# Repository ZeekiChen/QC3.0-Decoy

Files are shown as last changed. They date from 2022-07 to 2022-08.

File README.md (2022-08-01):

# QC3.0-Decoy
高精度QC3.0诱骗器  
2022.07.08  
项目发布，上传文件：  
CODE:  
  QC3.0 Decoy-Code-20220706.rar  
HARDWARE:  
  QC3.0 Decoy-Bom.xlsx  
  QC3.0 Decoy-PcbDoc.PcbDoc  
  QC3.0 Decoy-SchDoc.pdf  
  QC3.0 Decoy-丝印图.pdf  
QC3.0 Decoy-参考制作流程.pdf  
QC3.0 Decoy-使用说明.pdf  
QC3.0 Decoy-丝印图.rar  
2022.07.16  
修改Bom表，原Bom表中PMOS的选型Vgs太小，需要Vgs>20v  
涉及到的文件：QC3.0 Decoy-Bom.xlsx  
2022.07.25  
修改Gerber文件，补充NC Drill files  
2022.08.01  
添加固件，新增对使用SSD1312驱动芯片的OLED屏幕的支持  
修改文件名“QC3.0 Decoy-Code-20220706.rar”为“QC3.0 Decoy-Code-USECH1115-20220706.rar”  
上传文件“QC3.0 Decoy-Code-USESSD1312-20220801.rar”  
修改文件“QC3.0 Decoy-参考制作流程.pdf”，修改程序下载部分的固件选择相关说明

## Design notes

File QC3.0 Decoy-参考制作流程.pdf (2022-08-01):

# 制作准备

使用“\HARDWARE\QC3.0 Decoy.PcbDoc”文件打板，两层板，厚度 1.6mm 购买“\HARDWARE\QC3.0 Decoy-Bom.xlsx”表中的电子元器件和相关零件 准备一条 USB 转串口线用于程序烧录

# 一．焊接 PCB

由于板子设计的比较紧凑，每个元件的丝印丝印都被隐藏了，所以焊接板子的时候元件的参 数和位置，请打开“”“\HARDWARE\QC3.0 Decoy-丝印图.pdf”来查看。 焊接过程中需要注意的只有一点，如果你使用风枪进行吹焊，控制风枪温度在 240℃，屏幕 和输出接线端子最后焊接，PCB 背面阻焊开窗处补上一些锡来增加过电流能力。

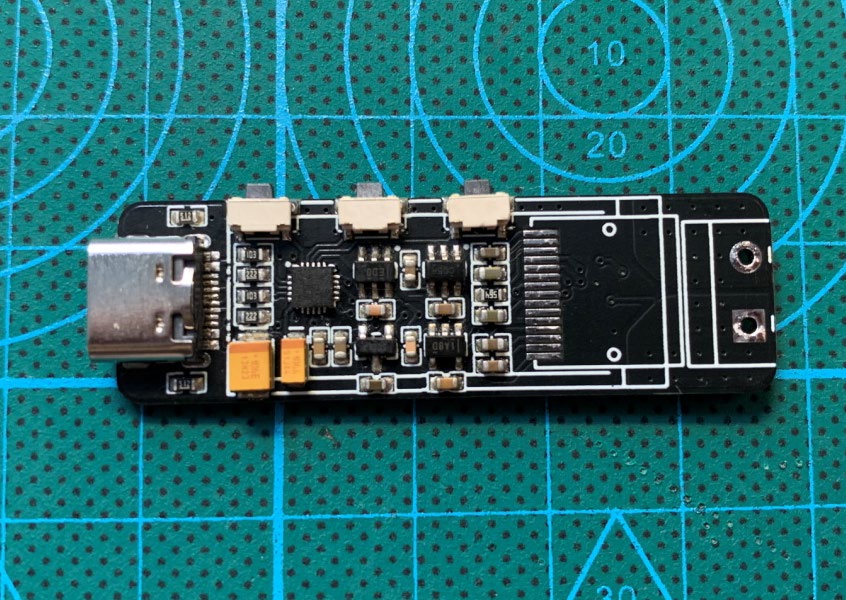
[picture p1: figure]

PCB 正面

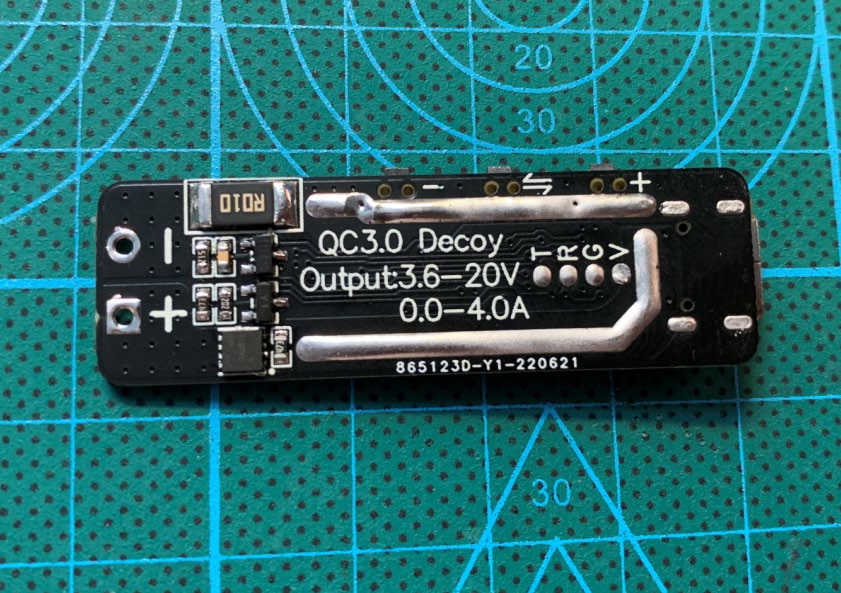
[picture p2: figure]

PCB 背面

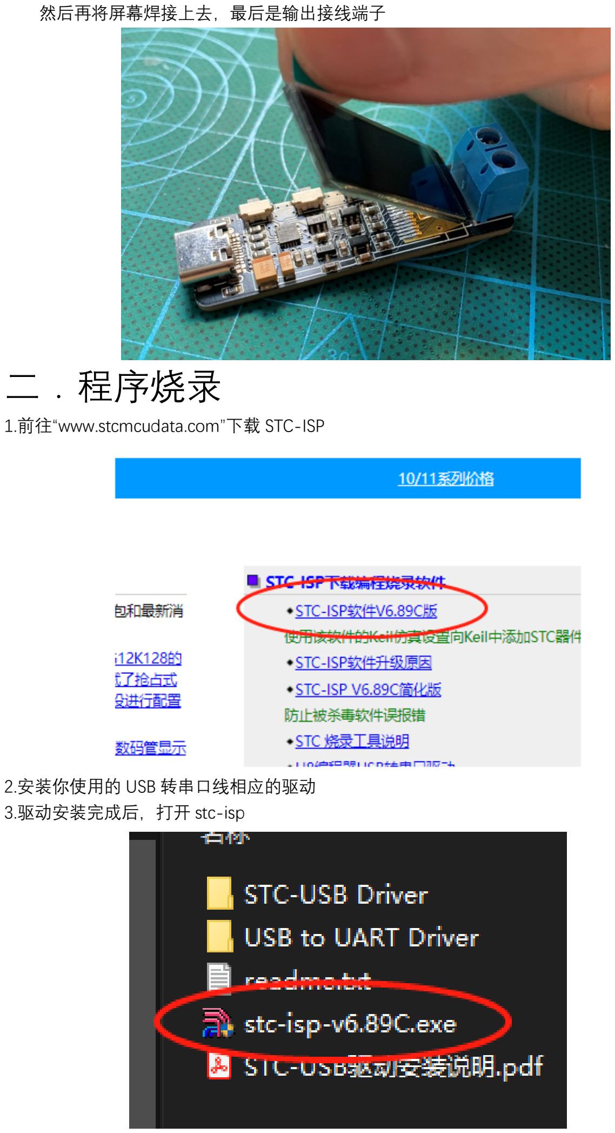
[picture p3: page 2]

然后再将屏幕焊接上去，最后是输出接线端子

# 二．程序烧录

1.前往“www.stcmcudata.com”下载 STC-ISP

2.安装你使用的 USB 转串口线相应的驱动
3.驱动安装完成后，打开 stc-isp

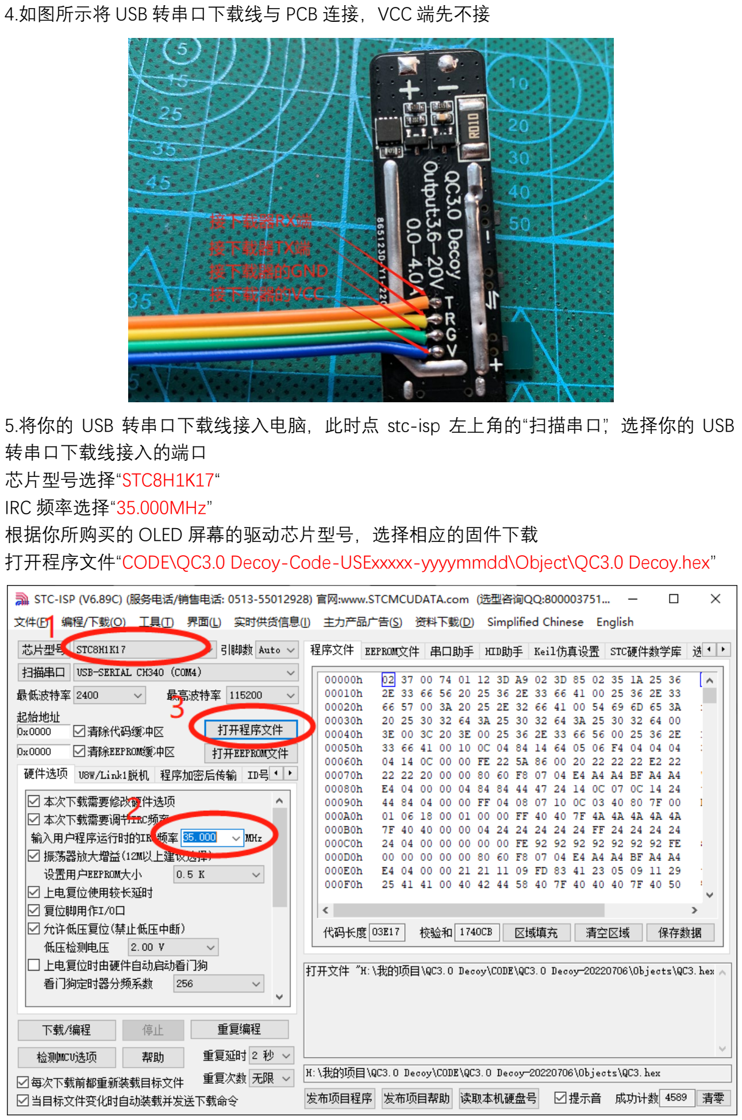
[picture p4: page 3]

4.如图所示将 USB 转串口下载线与 PCB 连接，VCC 端先不接

5.将你的 USB 转串口下载线接入电脑，此时点 stc-isp 左上角的“扫描串口”，选择你的 USB 转串口下载线接入的端口
芯片型号选择“STC8H1K17“
IRC 频率选择“35.000MHz”
根据你所购买的 OLED 屏幕的驱动芯片型号，选择相应的固件下载 打开程序文件“CODE\QC3.0 Decoy-Code-USExxxxx-yyyymmdd\Object\QC3.0 Decoy.hex”

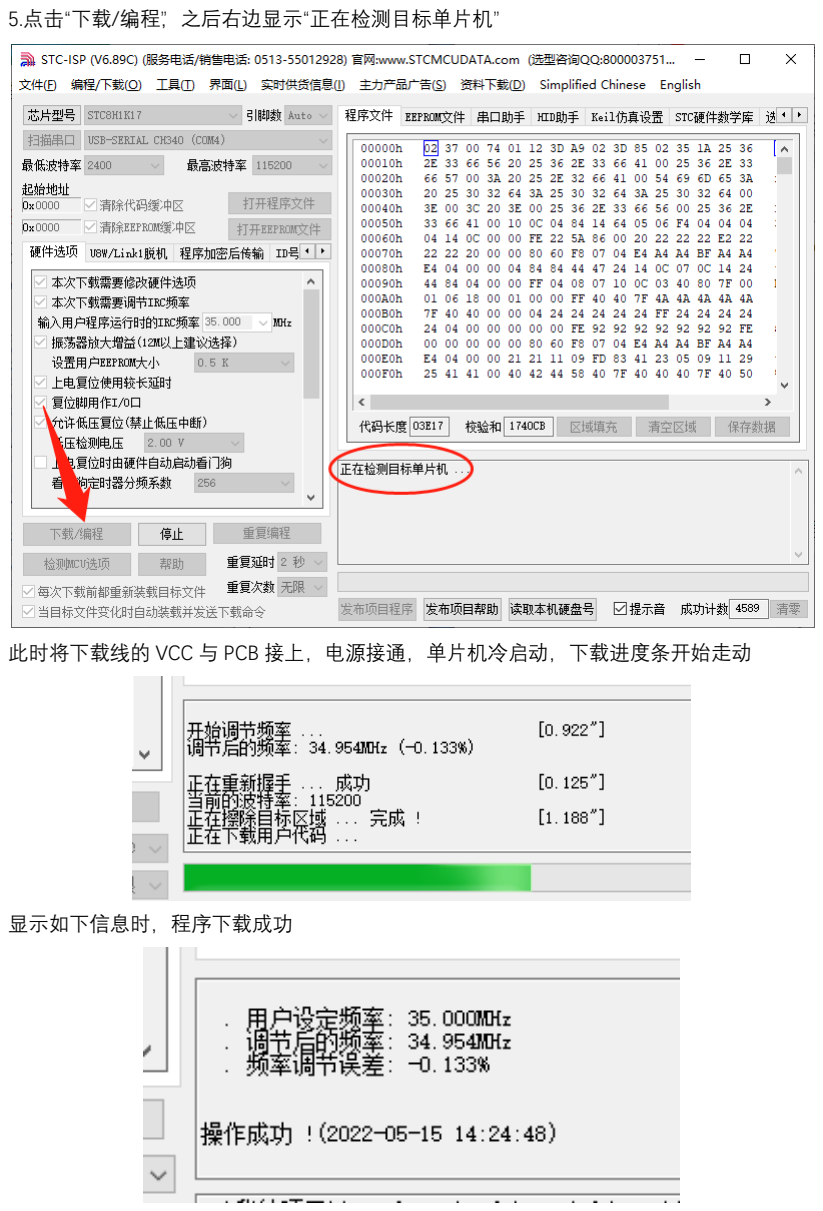
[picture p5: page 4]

5.点击“下载/编程”，之后右边显示“正在检测目标单片机”

此时将下载线的 VCC 与 PCB 接上，电源接通，单片机冷启动，下载进度条开始走动

显示如下信息时，程序下载成功

# 三．测试

将烧录好程序的 PCB，使用兼容 USB2.0 的 Type-C 线接入支持 QC3.0 快充协议的适配器或 者移动电源

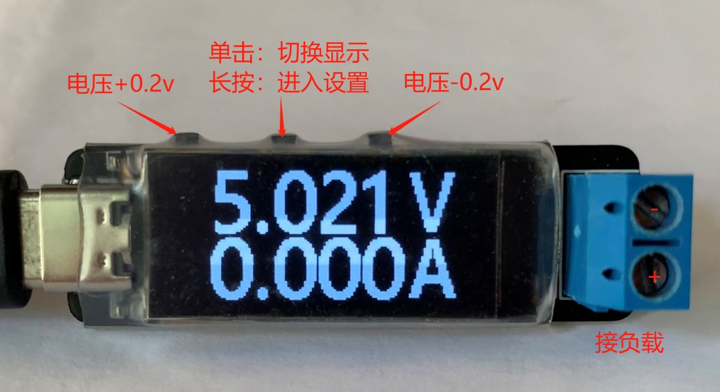
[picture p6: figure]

检查能否诱骗出电压，以及诱骗电压是否能调整，屏幕是否显示，现实的示数是否正常
1. 诱骗电压无法调整：原因可能是 Type-C 接口中 D+/D-端接触不良导致的，也可能是单 片机相应的控制引脚虚焊了
2. 屏幕不显示：原因可能是屏幕排线焊接不良，虚焊或者引脚间连锡，也可能是单片机相 应的控制引脚虚焊
3. 示数不正常：检查 U3,U4,U5 的焊接是否正常，也可能是单片机相应的控制引脚虚焊

# 四．封装

使用直径 13mm 的透明热缩管，裁剪至合适长度

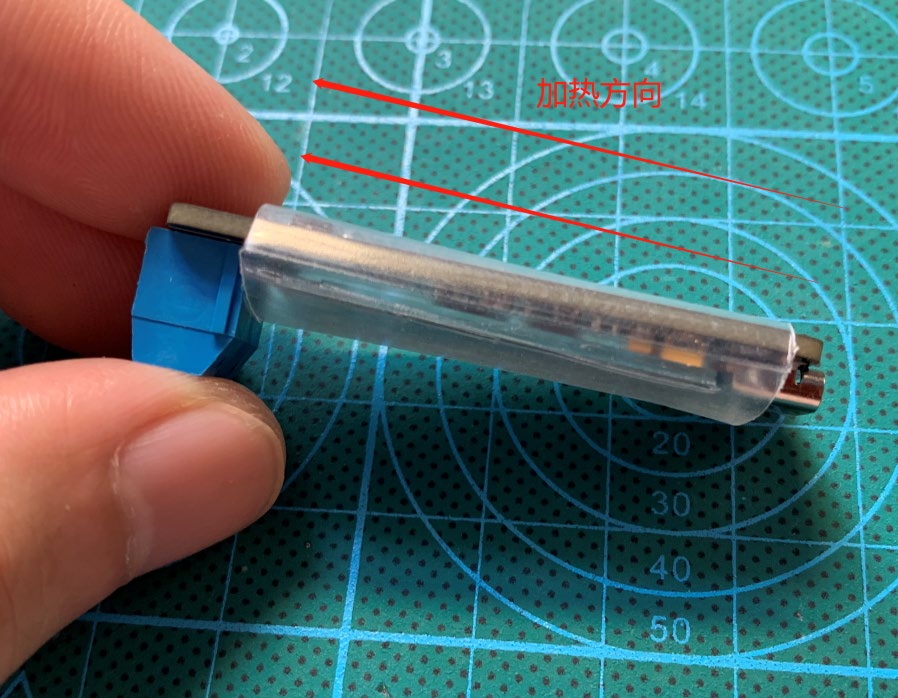
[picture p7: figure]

由于屏幕后端没有支撑，先加热有支撑的地方，使得屏幕与 PCB 平行固定之后，再加热屏 幕后端，注意温度不能过高，控制在 120℃左右，完成后如图所示：

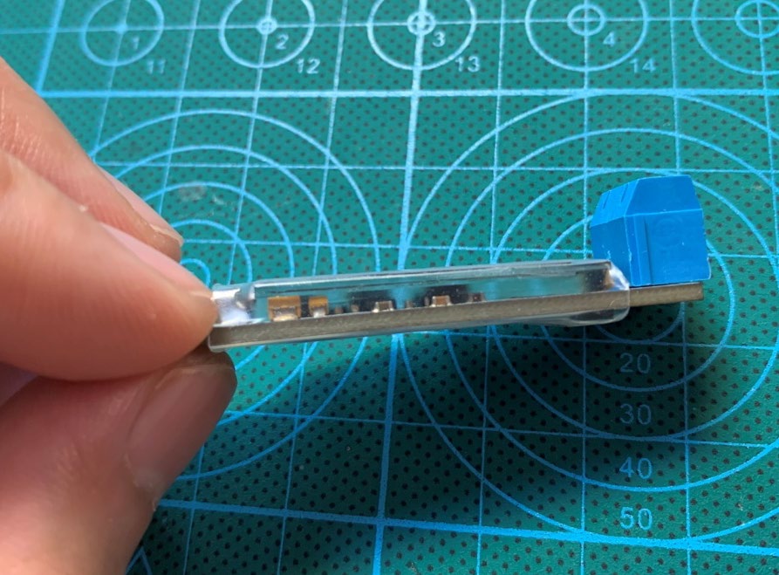
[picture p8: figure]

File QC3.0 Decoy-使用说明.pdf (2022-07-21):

# QC3.0 Decoy 使用说明

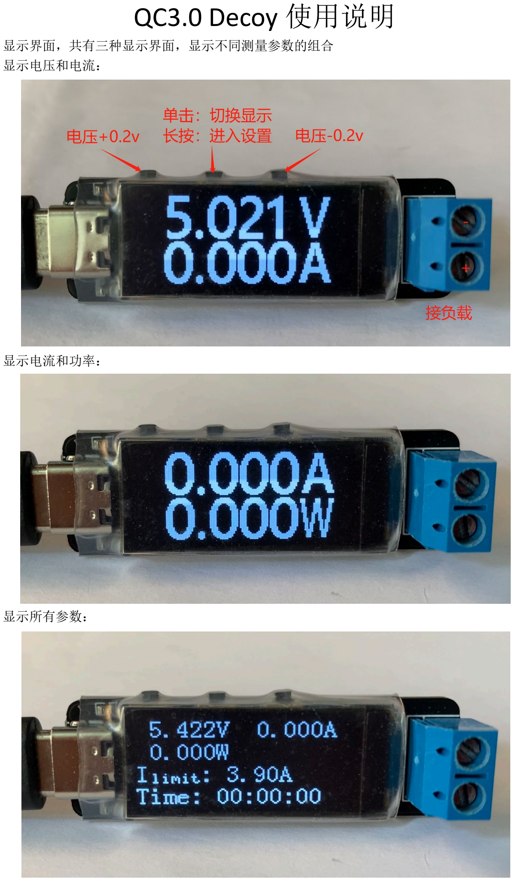
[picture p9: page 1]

显示界面，共有三种显示界面，显示不同测量参数的组合
显示电压和电流：

显示电流和功率：

显示所有参数：

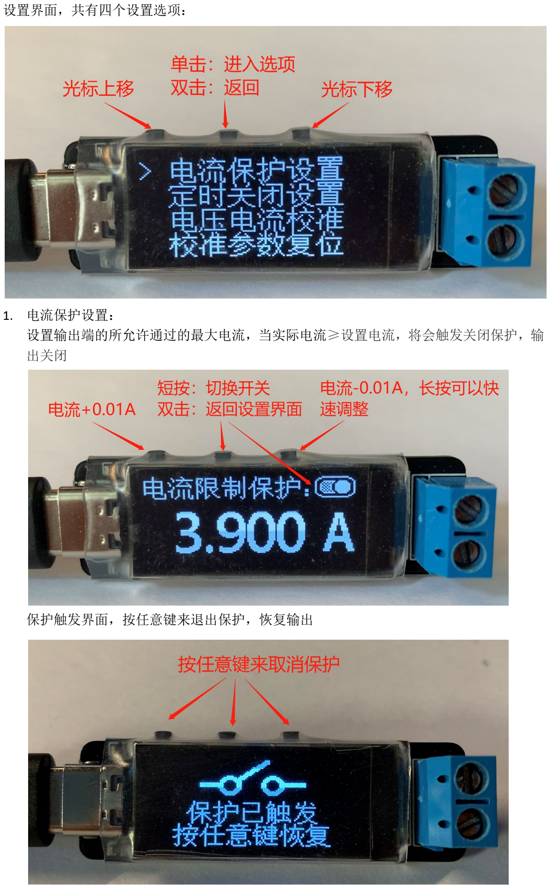
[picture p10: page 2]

设置界面，共有四个设置选项：

1. 电流保护设置：
设置输出端的所允许通过的最大电流，当实际电流≥设置电流，将会触发关闭保护，输 出关闭

保护触发界面，按任意键来退出保护，恢复输出

2. 定时关闭设置
设置多长时间后，输出关闭，单位为“时:分:秒”，可设置的最大时间为 99:59:59

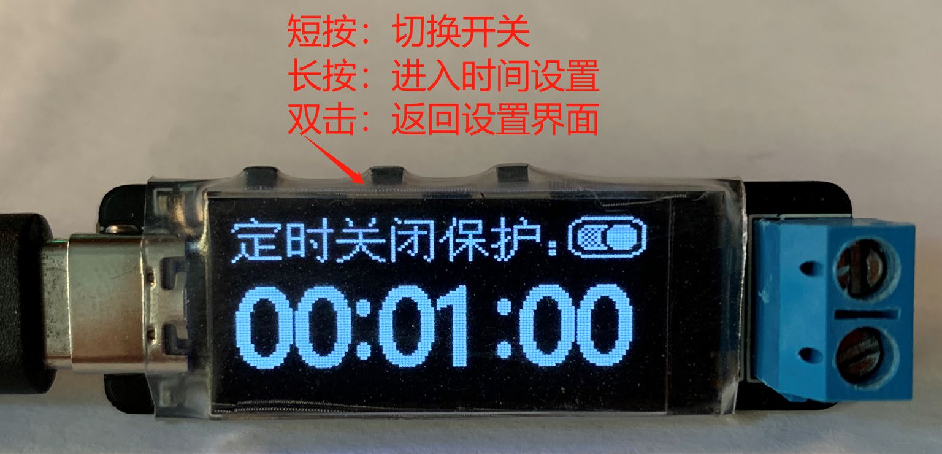
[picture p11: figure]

时间设置界面：（时间下面出现一个小箭头）

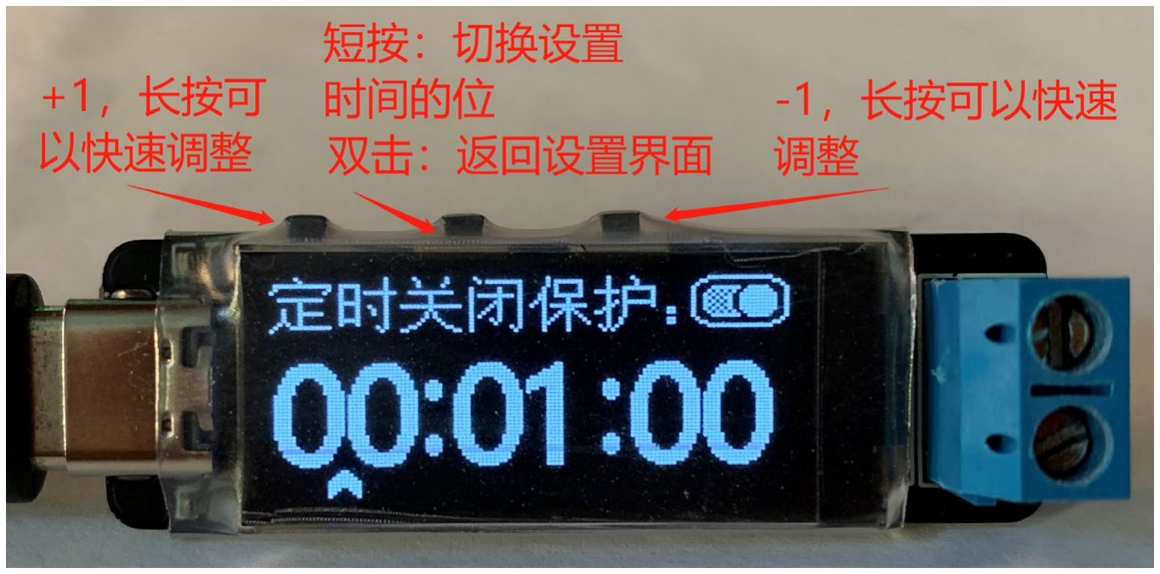
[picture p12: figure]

3. 电压电流校准设置
电压/电流校准，分别最大支持输入 10 个校准点（生成 9 个校准段） 校准分为四个步骤（电压和电流校准流程一致）
1） 选择当前是要校准电流还是电压，通过短按按键 2 来切换。短按按键 1 和按键 3 来 调整当前输出电压

2） 使用精度更高的表测得此时的实际电压Vactual
3） 长按按键 2，看到“< >”输入框消失，变成数字，此时通过按键 1 和按键 3 来输入Vactual

4） 输入完成后，双击按键 2 返回步骤 1），此时可进行下一个校准点的输入 请最少输入两个校准点（两个点才能生成一个段），本次校准才有效，双击按键 2 返回 设置界面的时候，会自动根据刚才输入的校准点生成校准段并保存 理论上你输入的校准点应该覆盖整个量程

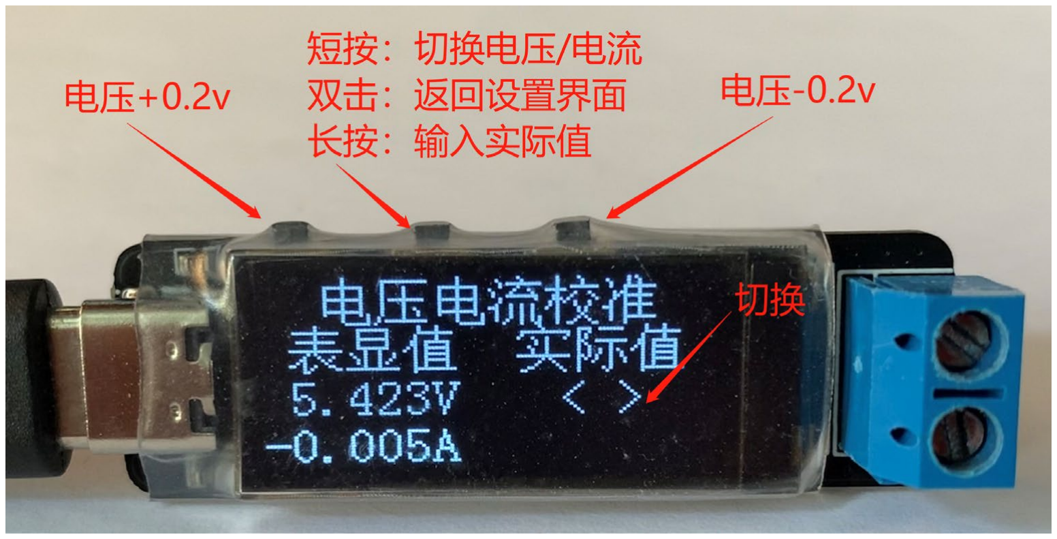
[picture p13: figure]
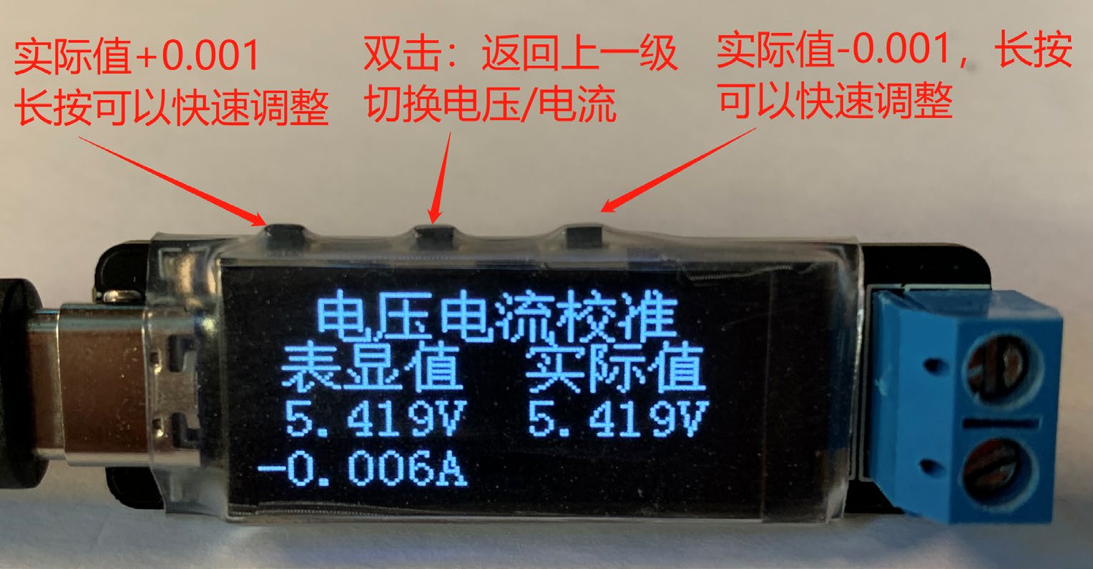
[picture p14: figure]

4. 校准参数复位设置
取消所有校准参数，设备回到未校准的状态

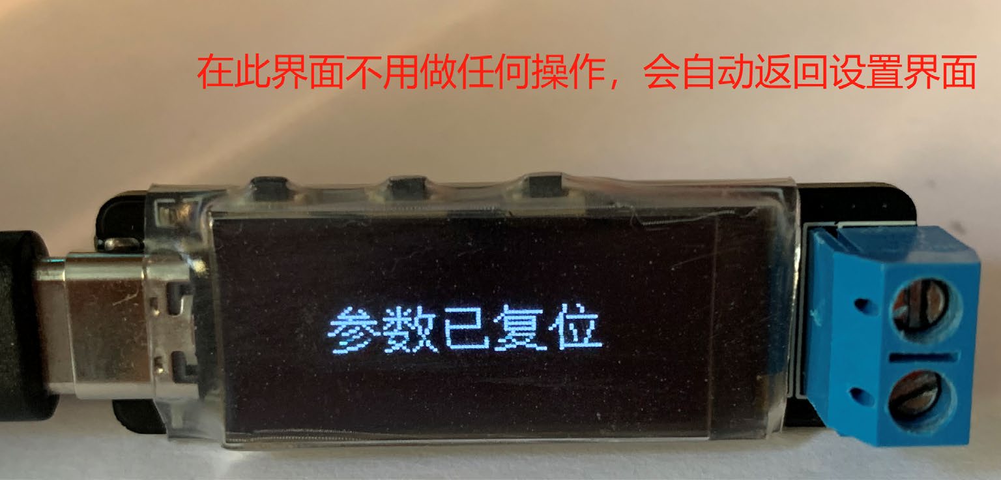
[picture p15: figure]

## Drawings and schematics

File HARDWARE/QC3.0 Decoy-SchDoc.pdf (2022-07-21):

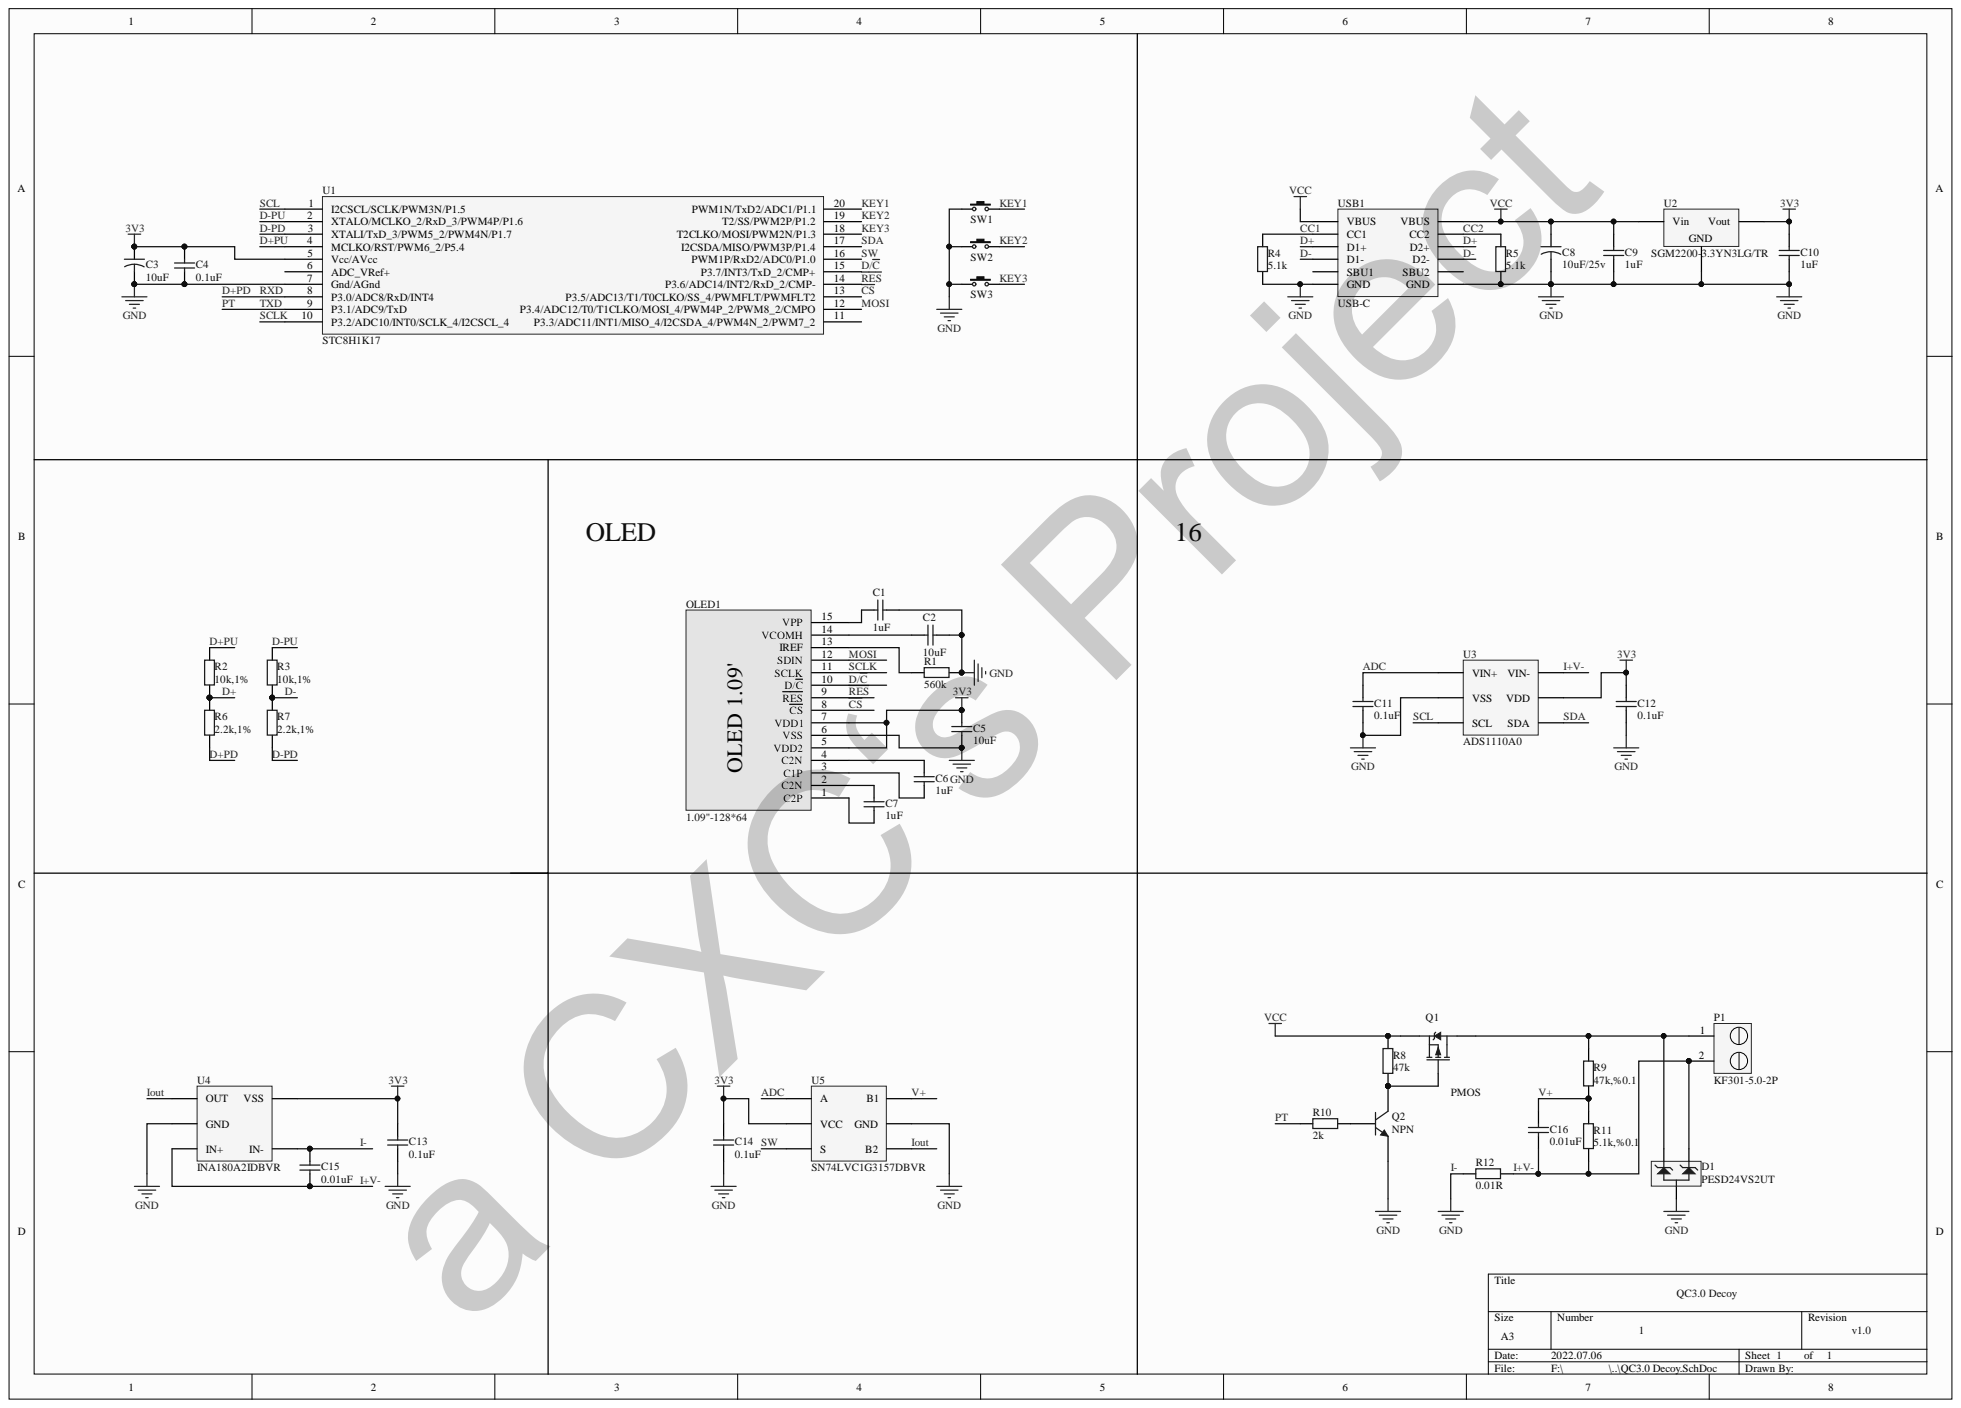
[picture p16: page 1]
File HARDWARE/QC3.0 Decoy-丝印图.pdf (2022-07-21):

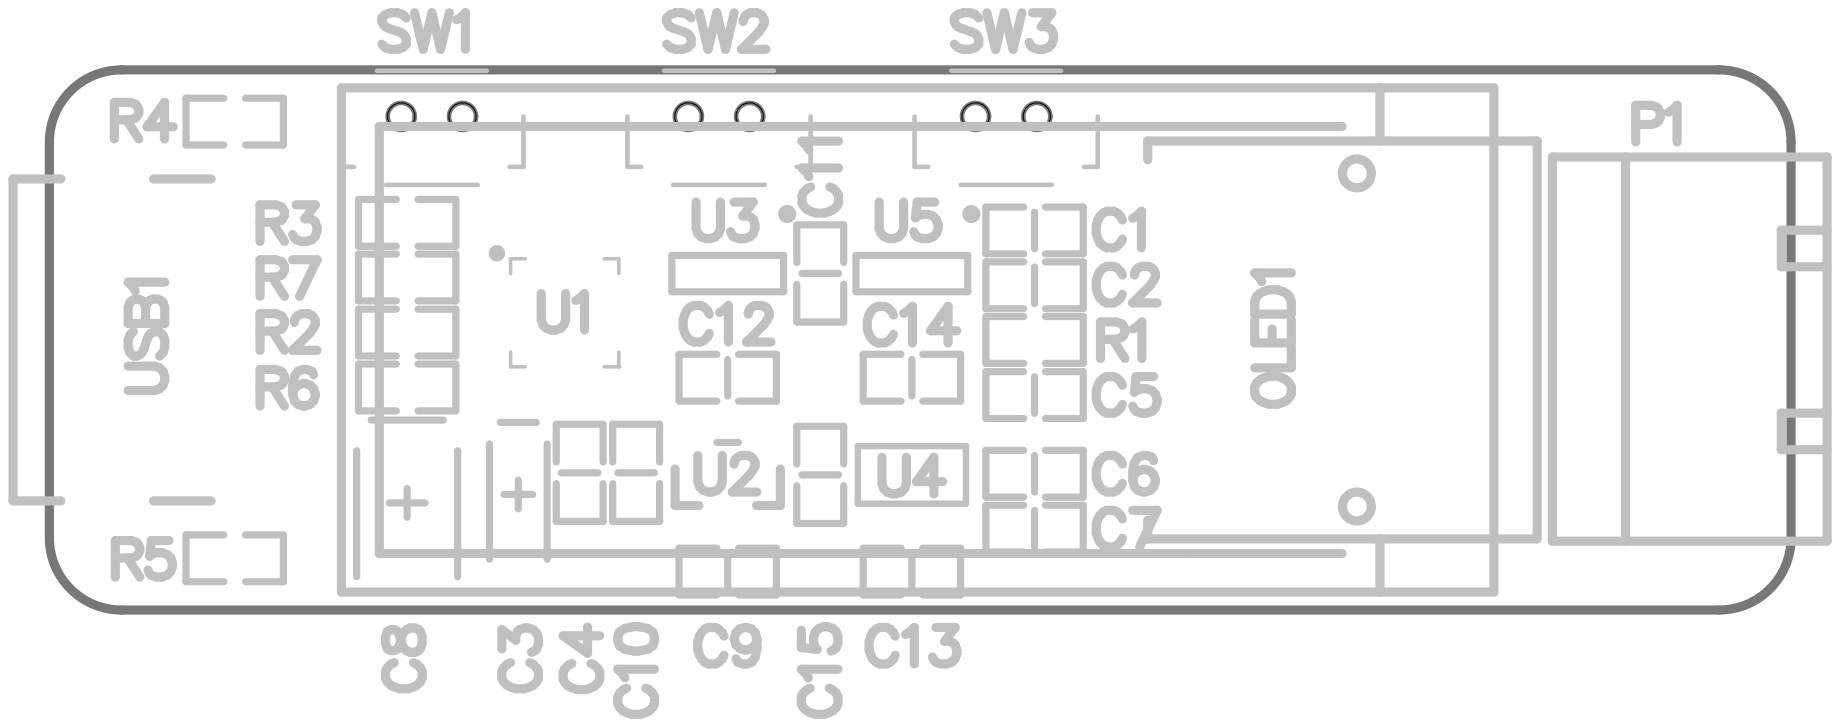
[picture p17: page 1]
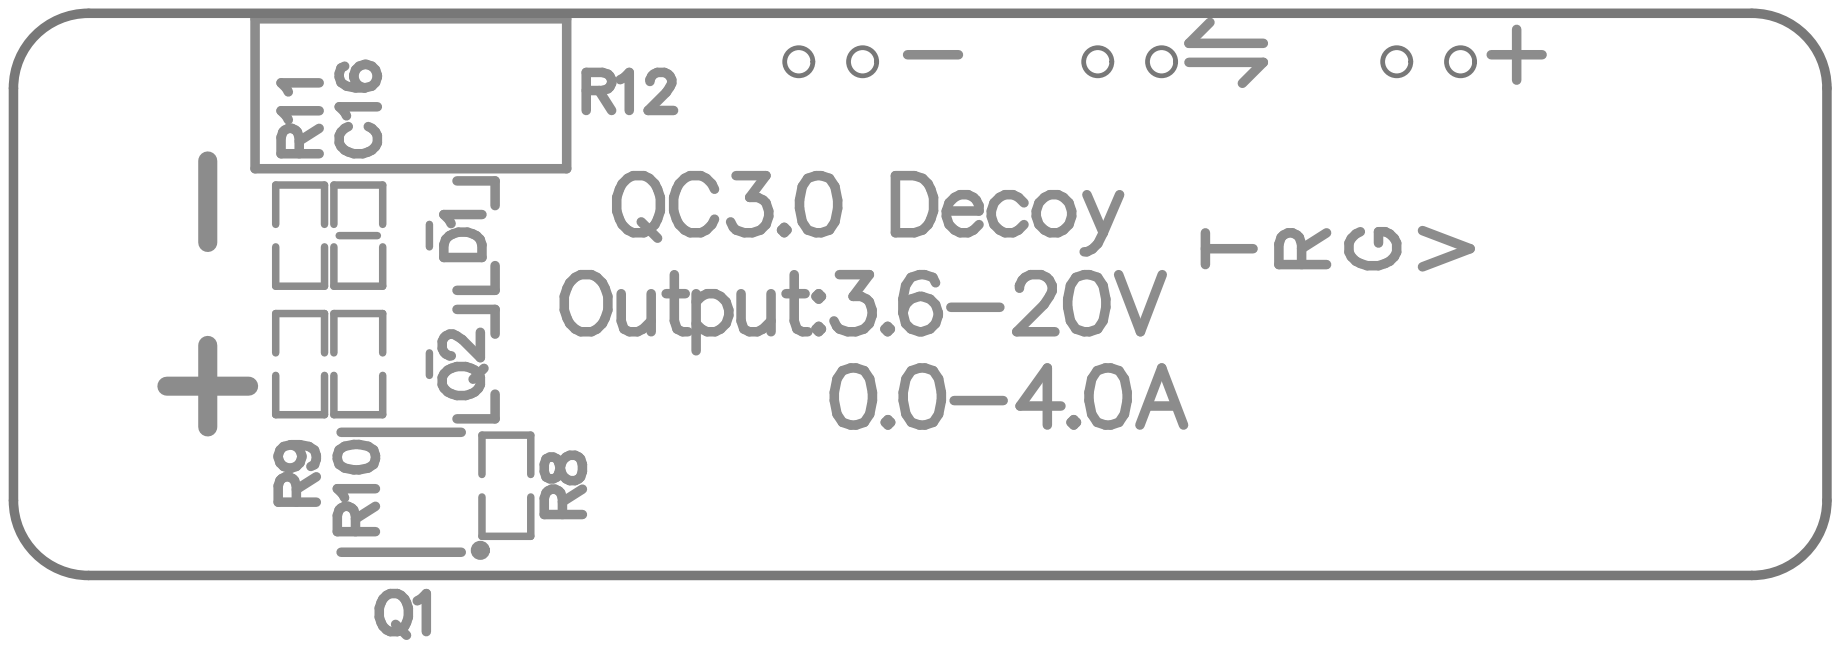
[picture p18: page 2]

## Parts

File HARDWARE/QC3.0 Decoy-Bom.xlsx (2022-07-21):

Comment | Description | Designator | Footprint | Quantity | 参考购买链接 | 参考单价
电容
0.01uF | 贴片陶瓷电容 | C15, C16 | C-0603-M | 2 | https://youxin-electronic.taobao.com/category-1145410923.htm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 | 0
0.1uF | 贴片陶瓷电容 | C4, C11, C12, C13, C14 | C-0603-M | 5 |  | 0
1uF | 贴片陶瓷电容 | C1, C6, C7, C9, C10 | C-0603-M | 5 |  | 0
10uF | 贴片陶瓷电容 | C2, C5 | C-0603-M | 2 |  | 0
10uF | 钽电容，耐压值>5v | C3 | C-3216-N | 1 | https://item.taobao.com/item.htm?spm=a1z10.3-c-s.w4002-21223910208.18.53cf6a4be3Ez4K&id=536882276924 | 0.27
10uF/25v | 钽电容，耐压值25v | C8 | C-3528-N | 1 | https://item.taobao.com/item.htm?spm=a1z10.3-c-s.w4002-21223910208.56.53cf6a4be3Ez4K&id=615804930789 | 0.7
电阻
2k | 贴片电阻，无精度要求 | R10 | R-0603-M | 1 | https://youxin-electronic.taobao.com/category-1171156354.htm?search=y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 | 0
5.1k | 贴片电阻，无精度要求 | R4, R5, R11 | R-0603-M | 2 |  | 0
47k | 贴片电阻，无精度要求 | R8 | R-0603-M | 1 |  | 0
560k | 贴片电阻，无精度要求 | R1 | R-0603-M | 1 |  | 0
10k,1% | 贴片电阻，精度%1 | R2, R3 | R-0603-M | 2 | https://item.taobao.com/item.htm?spm=a1z10.3-c-s.w4002-21223910208.13.447f6a4bPGRSEL&id=525777943950 | 0
2.2k,1% | 贴片电阻，精度%1 | R6, R7 | R-0603-M | 2 | https://item.taobao.com/item.htm?spm=a1z10.3-c-s.w4002-21223910208.14.66d26a4blAVt37&id=525826728150 | 0
47k,%0.1 | 贴片电阻，精度%0.1 | R9 | R-0603-M | 1 | https://item.taobao.com/item.htm?spm=a1z09.2.0.0.510c2e8dDr3MJp&id=632533483502&_u=7b2i1bf7b03 | 0
5.1k,%0.1 | 贴片电阻，精度%0.1 | R11 | R-0603-M | 1 | https://item.taobao.com/item.htm?spm=a1z09.2.0.0.510c2e8dDr3MJp&id=631867089215&_u=7b2i1bf8a1e | 0
0.01R | 合金分流电阻，±1% 1W | R12 | R-2512-L | 1 | https://item.taobao.com/item.htm?spm=a1z09.2.0.0.510c2e8dDr3MJp&id=565308949493&_u=7b2i1bf8ea7 | 0.38
二极管/三极管
PESD24VS2UT | Two-line ESD protection,24v | D1 | SOT-23 | 1 | https://item.taobao.com/item.htm?spm=a1z09.2.0.0.510c2e8dDr3MJp&id=662222739109&_u=7b2i1bf0aa1 | 0.19
S8050 | NPN型三极管，可使用其他通用NPN管代替 | Q2 | SOT-23 | 1 | https://item.taobao.com/item.htm?spm=a1z10.3-c-s.w4002-21223910208.11.1de06a4b10KE5Z&id=522577964105 | 0.06
AON7401 | P沟道场效应管，可使用Id>5A，Vgs>20v的其他同封装的管子代替，详情见备注 | Q1 | DFN-8_L3.0-W3.0-P0.65-BL_NCE3035Q | 1 | https://item.taobao.com/item.htm?spm=a1z09.2.0.0.4e332e8ddGfazO&id=613764374394&_u=gb2i1bfea15 | 1.5
集成芯片
SGM2200-3.3YN3LG/TR | 高输入电压LDO，Vin <= 26v, Vout = 3.3v | U2 | SOT-23 | 1 | https://item.taobao.com/item.htm?spm=a1z09.2.0.0.510c2e8dDr3MJp&id=584188275318&_u=7b2i1bfb589 | 0.52
SN74LVC1G3157DBVR | 双向导通，导通电阻6Ω，单刀双掷模拟开关 | U5 | SOT23-6L | 1 | https://item.taobao.com/item.htm?spm=a1z10.3-c-s.w4002-21223910208.26.f98b6a4bw0xBqy&id=581197005716 | 0.76
ADS1110A0IDBVR | 16位单通道差分输入ADC | U3 | SOT23-6L | 1 | https://item.taobao.com/item.htm?spm=a1z10.3-c-s.w4002-21223910208.9.2bf36a4bLv3vDo&id=634814183396 | 13.4
INA180A2IDBVR | 低侧和高侧电压输出电流感应放大器，增益=50 | U4 | SOT23-5 | 1 | https://item.taobao.com/item.htm?spm=a1z09.2.0.0.510c2e8dDr3MJp&id=594710766137&_u=7b2i1bfa87d | 0.93
STC8H1K17 | 增强型51单片机 | U1 | QFN20 3X3 | 1 | https://item.taobao.com/item.htm?spm=a1z10.3-c-s.w4002-21223910208.55.2c626a4bri9GJk&id=678239575525 | 2.7
其他
USB-C | USB-C型母接口,6PIN | USB1 | USB-C-SMD_16P | 1 | https://item.taobao.com/item.htm?spm=a1z09.2.0.0.510c2e8dDr3MJp&id=573090887123&_u=7b2i1bfdb73 | 0.32
Button | 轻触开关 | SW1, SW2, SW3 | TSW SMD-2*4*3.5 | 3 | https://item.taobao.com/item.htm?spm=a1z10.5-c-s.w4002-21223910190.18.467040e6S8H4Un&id=546690284515 | 0.1
KF301-5.0-2P | 接线端子，2P | P1 | KF301-5.0-2P | 1 | https://item.taobao.com/item.htm?spm=a1z09.2.0.0.510c2e8dDr3MJp&id=554756924317&_u=7b2i1bfd27b | 0.16
1.09"-128*64 | OLED12864屏幕 | OLED1 | OLED-1.09-15PIN - duplicate | 1 | https://item.taobao.com/item.htm?spm=a1z09.2.0.0.510c2e8dDr3MJp&id=589089608982&_u=7b2i1bfa738 | 9
透明热缩管 | 透明热缩管，12mm |  |  |  | https://item.taobao.com/item.htm?spm=a1z09.2.0.0.4e8f2e8dmsrntS&id=534010569395&_u=9b2i1bf3bd6
以上元器件在淘宝店铺：优信电子 基本可以买齐，有些器件比如：ADS1110A0,STC8H1K17可在其他淘宝店铺采购到更低的价格，但是可能不包邮反而不划算
AON7401替换料
AON7403
AON7409
AONR21307
AONR21321
AONR21357
